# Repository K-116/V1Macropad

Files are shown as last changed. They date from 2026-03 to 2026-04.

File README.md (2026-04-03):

# K116's hackpad 
this is my hackpad for blueprint, I added an oled, button and rotary encoder to the project. I used FreeCad and Tinkercad instead on Fusion360 the project file is avaliable <a href="https://github.com/K-116/V1Macropad/blob/main/CAD/k116finalproject.FCStd">here</a>

<h2>Here is a my 3d design</h2>



<h2>Schematic and PCB</h2>



<h2>Main takeaways</h2>
This project was definitely a learning experience, this was my first ever pcb and was my first time ever using KICAD. Although the tutorial used fusion 360, I learned that FreeCAD was much easier for me so I used that. I watched alot of Youtube videos to get the basics of KICAD (schematics, matrix, pcb routing) although connecting the 3d models to the components was a great challenge.

The main goal I had in mind was to make a Macropad that could adjust volume with the rotary encoder, link to youtube videos/music with the top two keys and copy,paste &select all with the bottom three. I designed the case to expose the pcb as I like to see my work and so I could fix any issues. :)

<h2>Final</h2>
I will make an additional section when I get the macropad!

made with ❤️ for blueprint

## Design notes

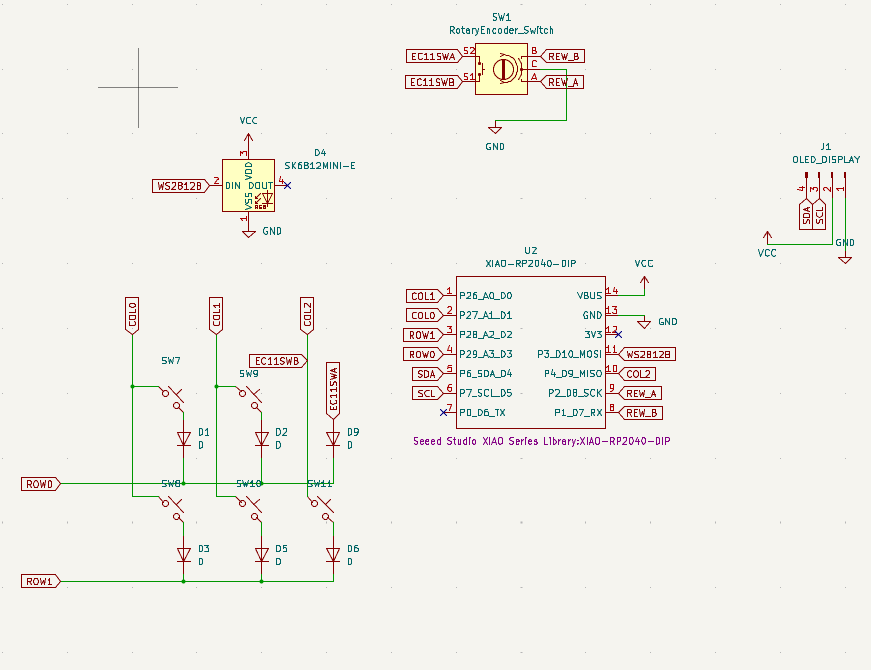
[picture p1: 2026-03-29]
PCB/schematic.png

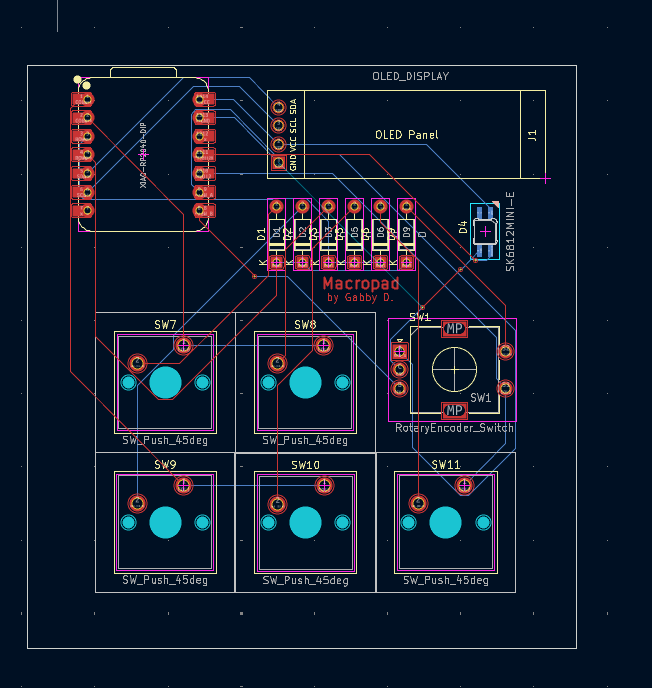
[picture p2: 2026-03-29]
PCB/pcbimage.png

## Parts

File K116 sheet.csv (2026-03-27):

Index | Listed name | Description | Quantity | Unit Price($) | Whole price ($) | Product Link
1 | (100pcs)100% original New 1N4148 IN4148 4148 DO-35 Chipset | Diodes | 100 | 0.0204 | 2.04 | https://www.aliexpress.com/item/3256807419851378.html?spm=a2g0n.shopcart.0.0.6bb438dasMdfve&mp=1
2 | Original Cherry MX Mechanical Keyboard Switch Speed silent pink axis mute red shaft RGB SMD 3 pin switch | Cherry MX mechanical switches | 4 | 1.5375 | 6.15 | https://www.aliexpress.com/item/3256801835610798.html?spm=a2g0n.shopcart.0.0.6bb438dasMdfve&mp=1
3 | WS2812B RGB LED Chip 5050SMD 10-1000PCS Black/White PCB WS2812 Individually Addressable Chip Pixels DC5V | LED | 10 | 0.0459 | 1.64 | https://www.aliexpress.com/item/2255801159561004.html?spm=a2g0n.shopcart.0.0.6bb438dasMdfve&mp=1
4 | RP2040-Zero RP2040 for Raspberry Pi Microcontroller PICO Development Board Module Dual-core Cortex M0 Processor 2MB Flash | RP2040-Zero | 1 | 3.34 | 3.34 | https://www.aliexpress.com/item/3256806637247373.html?spm=a2g0n.shopcart.0.0.6bb438dasMdfve&mp=1
5 | 5PCS/LOT 20 Position 360 Degree Rotary Encoder EC11 w Push Button 5Pin Handle Long 15/20MM With A Built In Push Button Switch | Rotary encoder | 5 | 0.1109 | 0.99 | https://www.aliexpress.com/item/3256801237549169.html?spm=a2g0n.shopcart.0.0.6bb438dasMdfve&mp=1
6 | 0.91 inch OLED Module White/Blue OLED 128X32 OLED LCD LED Display Module 0.91" IIC Communicate For Arduino ROHS | 0.91" OLED screen | 1 | 5.21 | 5.21 | https://www.aliexpress.com/item/3256806165075447.html?spm=a2g0n.shopcart.0.0.6bb438dasMdfve&mp=1
7 | PCB |  | 5 | 3.196 | 5.3 | https://github.com/K-116/V1Macropad
8 | 3d printed case |  | 1 | x | $6.00
9 | M3x16mm Screws |  | 50 | 0.0198 | $0.99 | https://www.aliexpress.us/item/3256808523663879.html?mp=1
10 | M3 Heatset Inserts |  | 50 | 0.066 | 3.3 | https://www.aliexpress.us/item/3256804349544912.html?mp=1

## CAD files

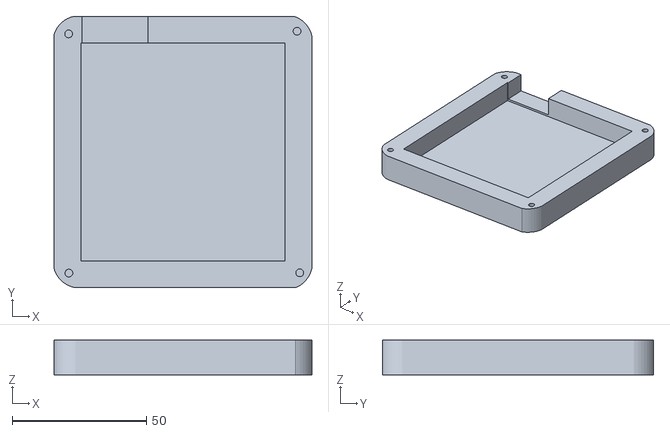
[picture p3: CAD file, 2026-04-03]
CAD/case_base.stl
96.0 x 101.0 x 13.0

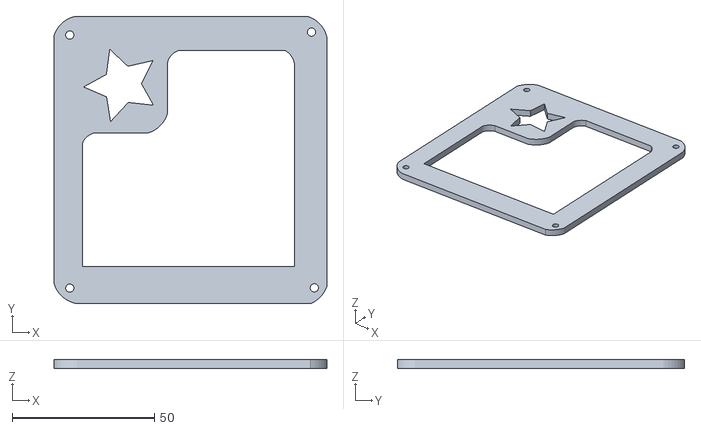
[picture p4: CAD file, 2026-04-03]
CAD/case_lid.stl
96.0 x 101.0 x 3.00

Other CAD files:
CAD/k116finalproject.FCStd
CAD/K116-Hackpad.step

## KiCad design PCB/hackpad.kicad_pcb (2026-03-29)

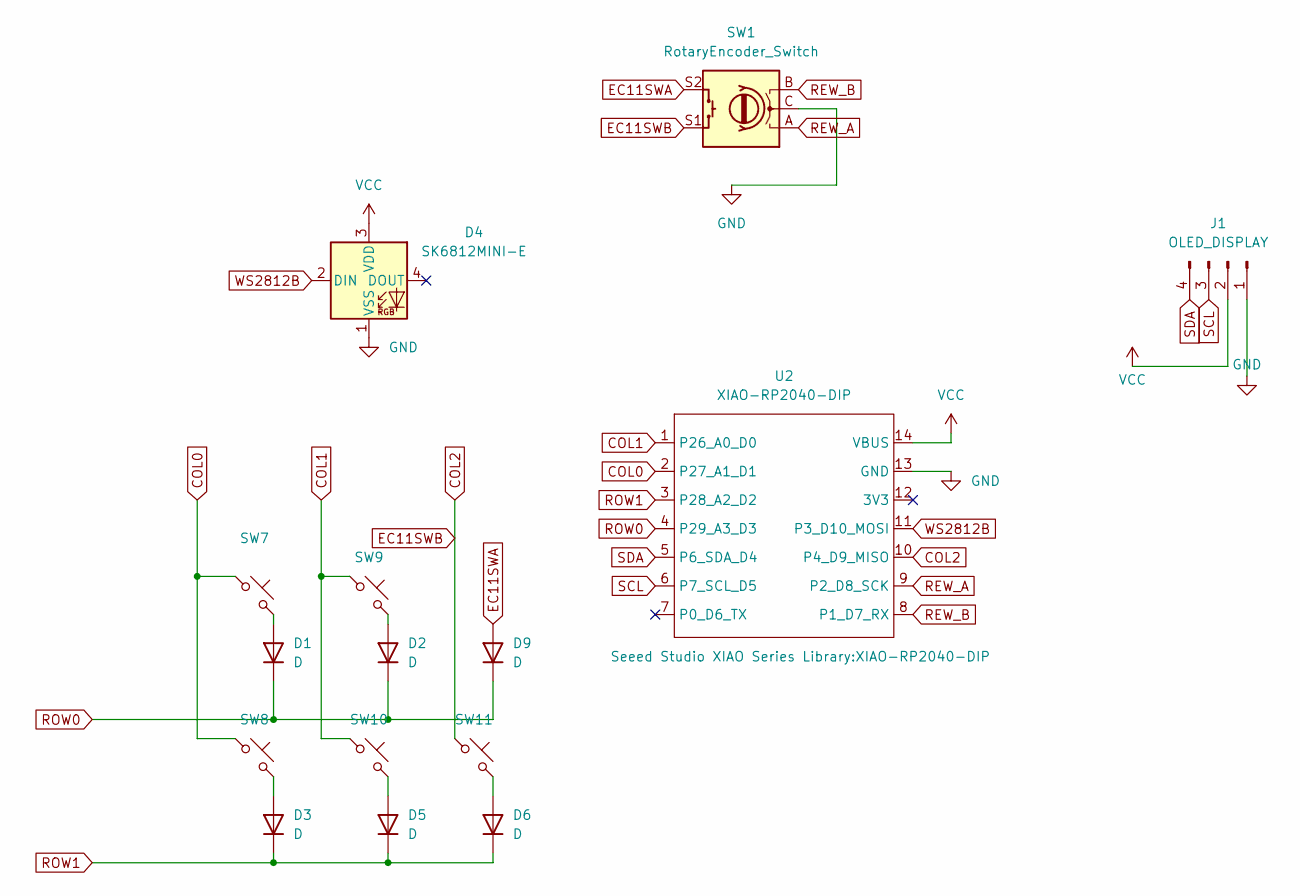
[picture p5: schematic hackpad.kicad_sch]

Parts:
D1, D2, D3, D5, D6, D9: D; D_DO-35_SOD27_P7.62mm_Horizontal
D4: SK6812MINI-E; SK6812MINI-E_fixed
J1: OLED_DISPLAY; SSD1306-0.91-OLED-4pin-128x32(1)
SW1: RotaryEncoder_Switch; RotaryEncoder_Alps_EC11E-Switch_Vertical_H20mm
SW7, SW8, SW9, SW10, SW11: SW_Push_45deg; SW_Cherry_MX_1.00u_PCB
U2: XIAO-RP2040-DIP

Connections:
COL0: SW7.1, SW8.1, U2.2 (P27_A1_D1)
COL1: SW9.1, SW10.1, U2.1 (P26_A0_D0)
COL2: SW1.S1, SW11.1, U2.10 (P4_D9_MISO)
EC11SWA: D9.2 (A), SW1.S2
GND: D4.1 (VSS), J1.1, SW1.C, U2.13 (GND)
unnamed: D1.2 (A), SW7.2
unnamed: D2.2 (A), SW9.2
unnamed: D3.2 (A), SW8.2
unnamed: D5.2 (A), SW10.2
unnamed: D6.2 (A), SW11.2
REW_A: SW1.A, U2.9 (P2_D8_SCK)
REW_B: SW1.B, U2.8 (P1_D7_RX)
ROW0: D1.1 (K), D2.1 (K), D9.1 (K), U2.4 (P29_A3_D3)
ROW1: D3.1 (K), D5.1 (K), D6.1 (K), U2.3 (P28_A2_D2)
SCL: J1.3, U2.6 (P7_SCL_D5)
SDA: J1.4, U2.5 (P6_SDA_D4)
VCC: D4.3 (VDD), J1.2, U2.14 (VBUS)
WS2812B: D4.2 (DIN), U2.11 (P3_D10_MOSI)

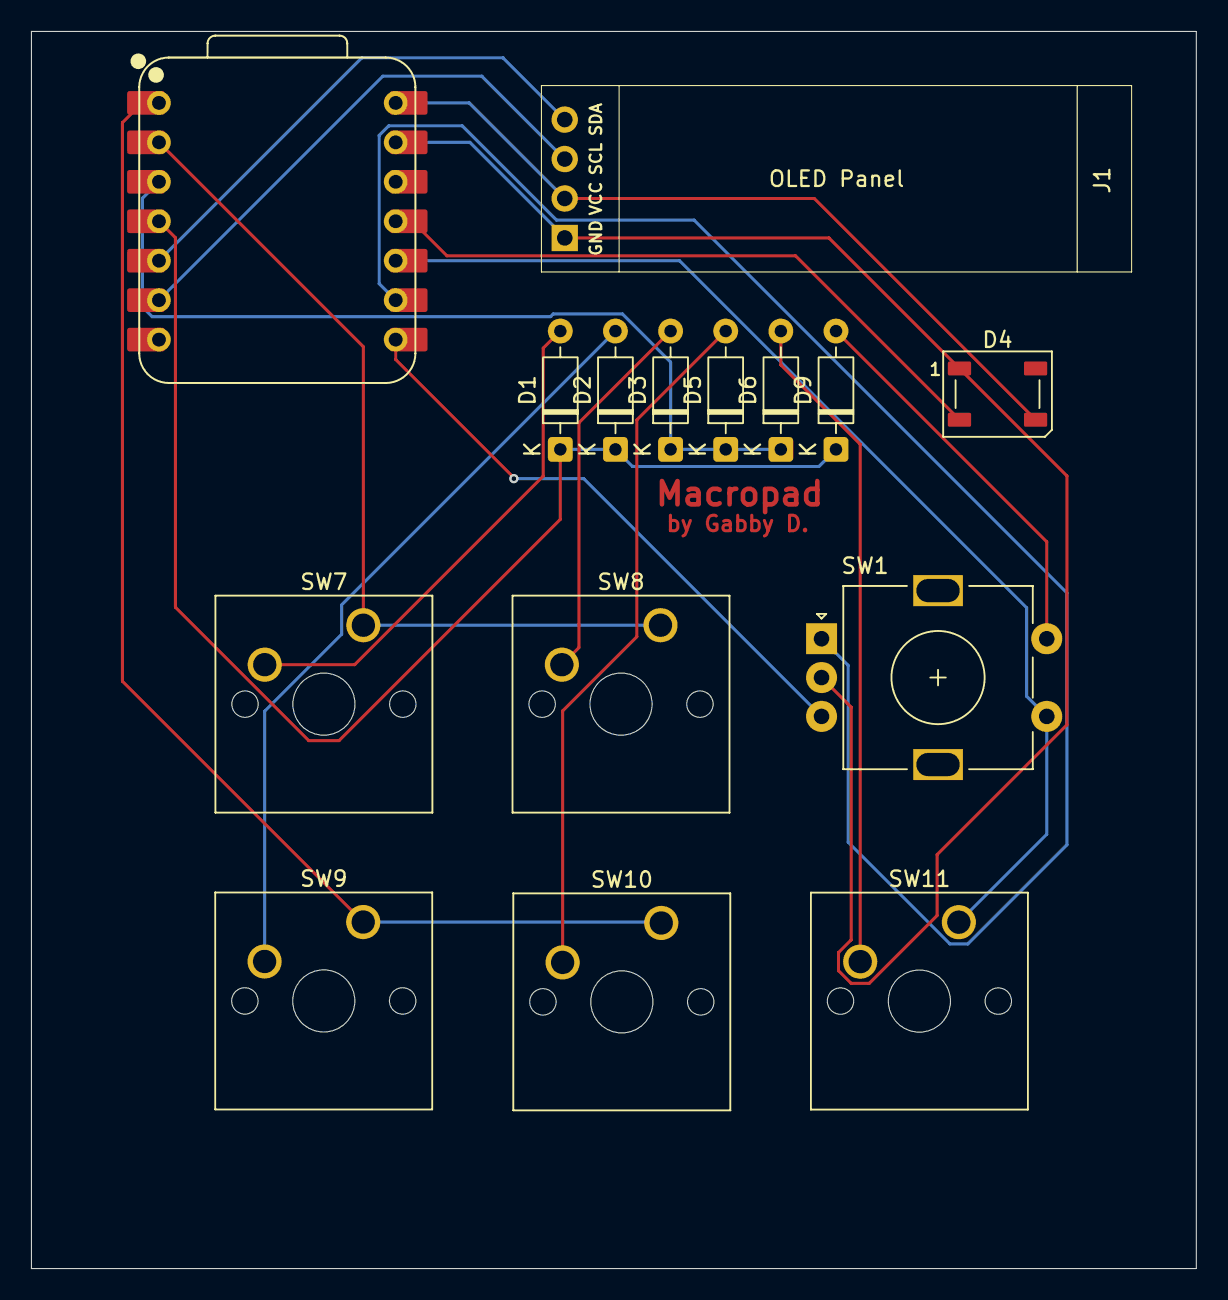
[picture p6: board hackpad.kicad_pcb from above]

Board: 2 copper layers, 75.0 x 79.7 mm, 15 parts (0 on the bottom side), 18 nets.

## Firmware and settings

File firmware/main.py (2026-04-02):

import board

from kmk.kmk_keyboard import KMKKeyboard
from kmk.keys import KC
from kmk.scanners import DiodeOrientation
from kmk.modules.layers import Layers
from kmk.modules.encoder import EncoderHandler
from kmk.extensions.media_keys import MediaKeys
from kmk.extensions.RGB import RGB, AnimationModes
from kmk.macros.simple import SimpleMacro

# Initialize the Keyboard
keyboard = KMKKeyboard()

# --- HARDWARE CONFIGURATION ---

# 1. SWITCH MATRIX (2 rows x 3 columns = 6 positions, using 5)
keyboard.col_pins = (board.D1, board.D0, board.D4)  # 3 columns
keyboard.row_pins = (board.D2, board.D3)            # 2 rows
keyboard.diode_orientation = DiodeOrientation.COL2ROW

# 2. ROTARY ENCODER (Volume control)
encoder_handler = EncoderHandler()
keyboard.modules.append(encoder_handler)
# Pin A = D6, Pin B = D7, Button = D8 (push-to-mute)
encoder_handler.pins = ((board.D6, board.D7, board.D8, False),)



# 4. MODULES & EXTENSIONS
keyboard.modules.append(Layers())
keyboard.extensions.append(MediaKeys())

# --- MACROS ---

# YouTube URL macro - types the URL when pressed
youtube_macro = SimpleMacro(
    text="https://www.youtube.com\n",  # \n presses Enter after typing
    use_interval=False,
    interval=0,
)

# --- KEY LAYOUT ---
# Physical layout:
# TOP ROW:     [Play/Pause]  [YouTube URL]
# BOTTOM ROW:  [Copy]        [Paste]        [Select All]
#
# Matrix layout (2 rows x 3 columns):
# Row 0 (Top):     [0,0] = Play/Pause    [0,1] = YouTube    [0,2] = Unused
# Row 1 (Bottom):  [1,0] = Copy          [1,1] = Paste       [1,2] = Select All

keyboard.keymap = [
    # Default Layer
    [
        # Row 0 (Top row - 2 buttons)
        KC.MPLY,                    # [0,0] Top-Left: Play/Pause
        youtube_macro,              # [0,1] Top-Right: Types youtube.com URL
        KC.NO,                      # [0,2] Top-Right corner: Not used
        
        # Row 1 (Bottom row - 3 buttons)
        KC.LCTL(KC.C),              # [1,0] Bottom-Left: Copy (Ctrl+C)
        KC.LCTL(KC.V),              # [1,1] Bottom-Middle: Paste (Ctrl+V)
        KC.LCTL(KC.A),              # [1,2] Bottom-Right: Select All (Ctrl+A)
    ]
]

# --- ENCODER MAP ---
# Encoder always controls volume regardless of layer
encoder_handler.map = [
    ((KC.VOLU, KC.VOLD, KC.MUTE),),  # Volume Up/Down, Mute on click
]

if __name__ == '__main__':
    keyboard.go()

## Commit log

2026-03-24 Create pcb
2026-03-26 Initialize keyboard with hardware configuration
    Set up keyboard configuration with encoder and RGB support.
2026-03-26 Add K116 Hackpad STEP file
    [K116-Hackpad.step]
